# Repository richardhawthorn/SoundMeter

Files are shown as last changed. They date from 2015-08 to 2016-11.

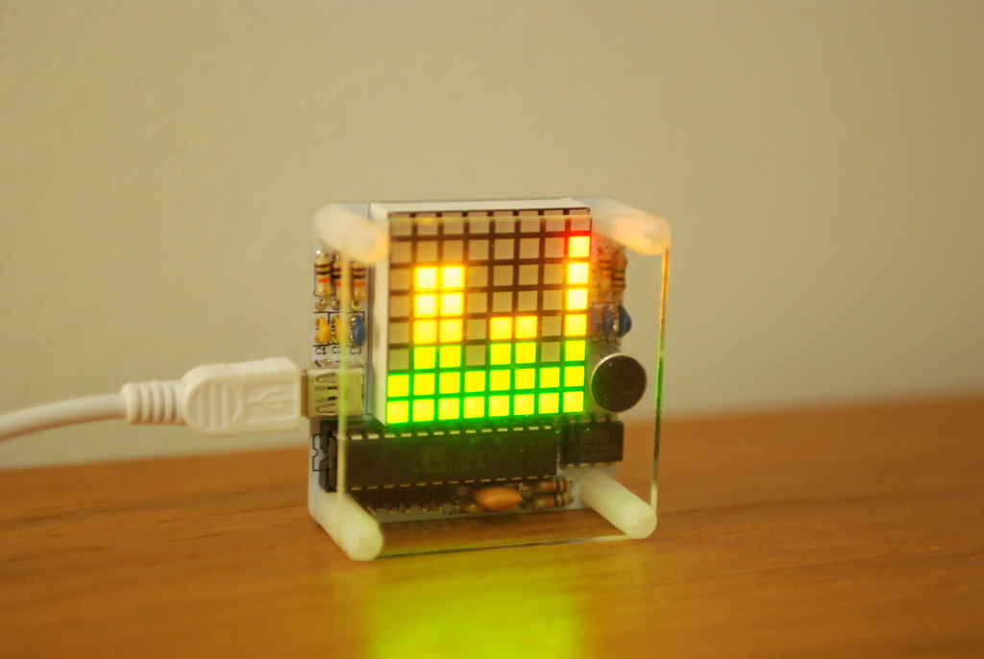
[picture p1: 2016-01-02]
images/DSC_5983.JPG

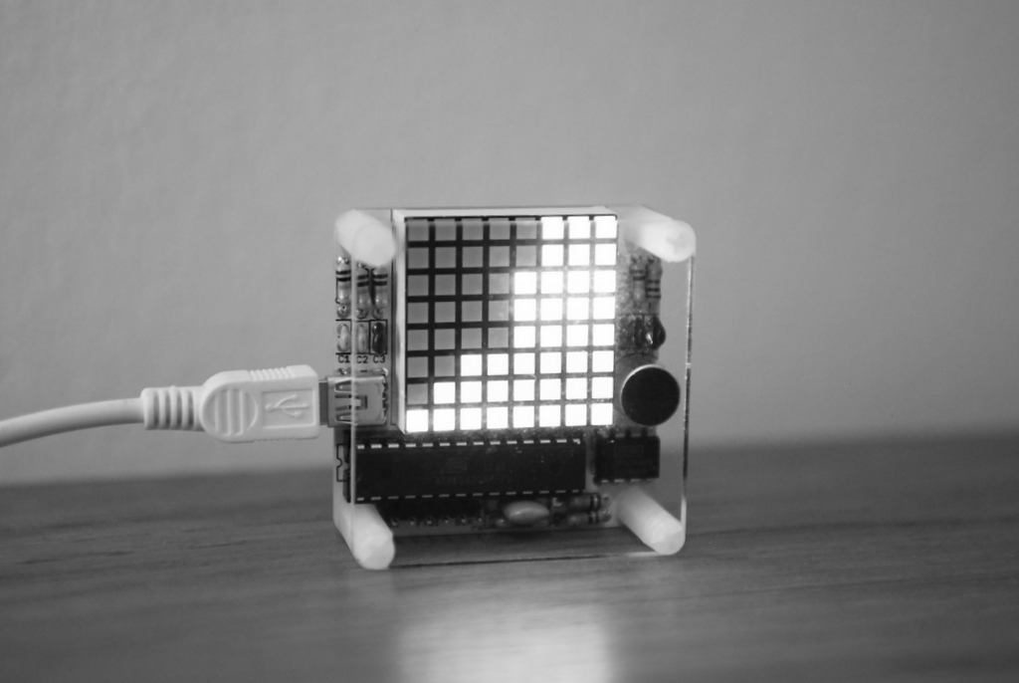
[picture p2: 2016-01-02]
images/DSC_5989.JPG

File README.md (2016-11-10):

### Description

PCB and Arduino code for a sound level meter.  Can be used as a spectrum analyser, or as a scrolling sound level meter.

### Features

- Bi-colour 8x8 LED matrix
- Microphone and built in amplifier
- ATMEGA328P with Arduino boot-loader
- 5V operation @ 16Mhz
- Mini USB power connector
- FTDI programming port
- ICSP port

### License

This work is licensed under a Creative Commons Attribution-ShareAlike 4.0 International License.

<br />
Designed by <a xmlns:cc="http://creativecommons.org/ns#" href="http://www.richardhawthorn.com" property="cc:attributionName" rel="cc:attributionURL" target="_blank">Richard Hawthorn</a><br />
<a rel="license" href="http://creativecommons.org/licenses/by-sa/4.0/" target="_blank">View License</a>

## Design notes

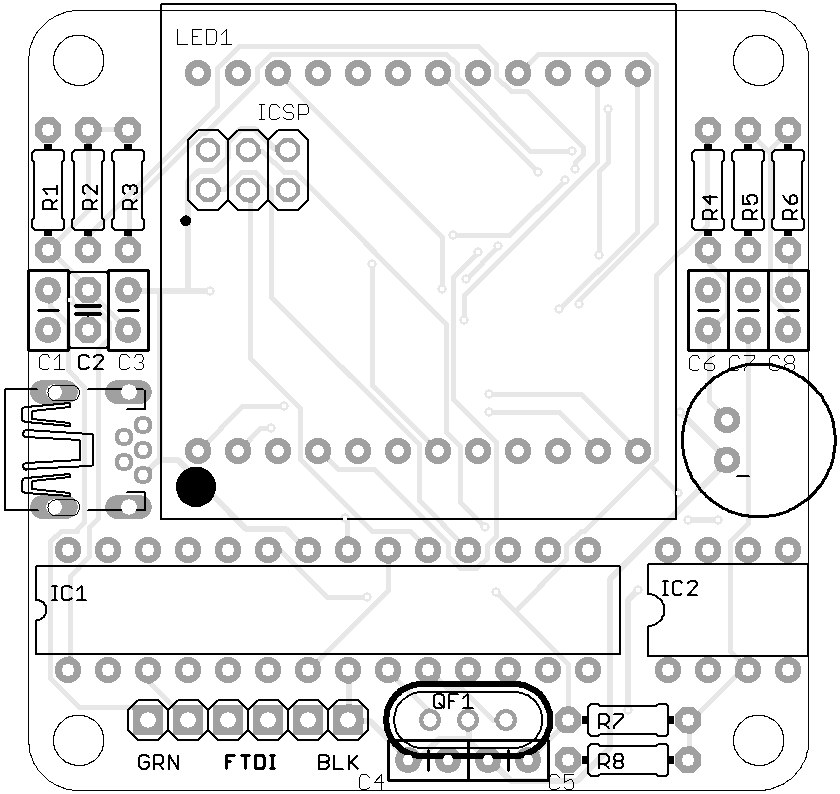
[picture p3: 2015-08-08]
images/pcb_front.png

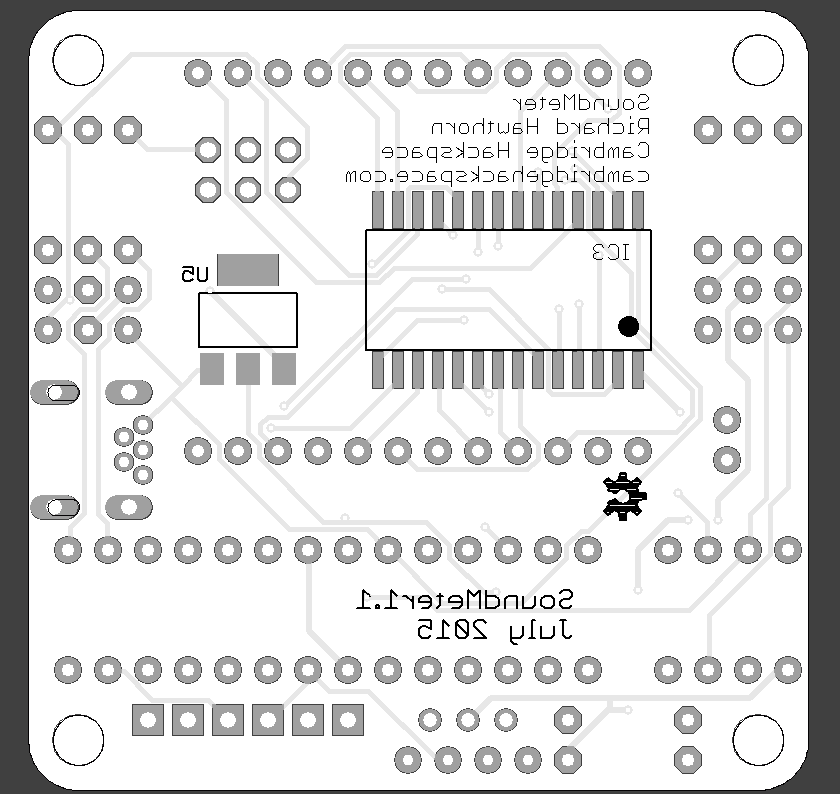
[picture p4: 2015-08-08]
images/pcb_back.png

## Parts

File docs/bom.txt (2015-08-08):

Qty Value      Device                                       Package                    Parts              Description                                                    
1              DISP_SEGMENT_8X8_BICOLOR                     SEGMENT_BICOL              LED1               8x8 Bi-Color LED Segment Displays: Row = Cathode               
3   0.1uf      CAPPTH2                                      CAP-PTH-SMALL2             C1, C2, C4, C5     Capacitor                                                                                          
5   10K        R-US_0204/7                                  0204/7                     R1, R2, R3, R7, R8 RESISTOR, American symbol                                      
1   10k        R-US_0204/7                                  0204/7                     R5                 RESISTOR, American symbol                                      
1   10uf       CAPPTH2                                      CAP-PTH-SMALL2             C3                 Capacitor                                                      
1   12pf       CAPPTH2                                      CAP-PTH-SMALL2             C8                 Capacitor                                                      
1   1M         R-US_0204/7                                  0204/7                     R6                 RESISTOR, American symbol                                      
1   1uf        CAPPTH2                                      CAP-PTH-SMALL2             C7                 Capacitor                                                      
1   28-SOIC    HT16K33_SOP28                                SOP28_300MIL               IC3                                                                               
1   2k2        R-US_0204/7                                  0204/7                     R4                 RESISTOR, American symbol                                      
1   4.7uf      CAPPTH2                                      CAP-PTH-SMALL2             C6                 Capacitor                                                      
1   8M10AHC49T 8M10AHC49T                                   HC49U                      QF1                Monolithic Crystal Filters                                     
1   ATMEGA     ATMEGA168PROUND                              DIL28-3-ROUND              IC1                MICROCONTROLLER                                                
1   FTDI       PINHD-1X6                                    1X06                       CN4                PIN HEADER                                                     
1   ICSP       PINHD-2X3                                    2X03                       ICSP1              PIN HEADER                                                     
1   MIC9.7MM   MIC9.7MM                                     MIC-9.7MM                  U$6                Omni-directional electret microphone. 9.7mm standard diameter. 
1   OPA344     OPA344                                       DIL08                      IC2                OPA344                                                         
1   REG1117    REG1117                                      SOT223                     U5                 800mA and 1A Low Dropout (LDO) Positive Regulator              
1   USB        MINI-USB_SHIELD5P2-32005-601                 32005-601                  X1                 MINI USB-B R/A DIP 5pol.

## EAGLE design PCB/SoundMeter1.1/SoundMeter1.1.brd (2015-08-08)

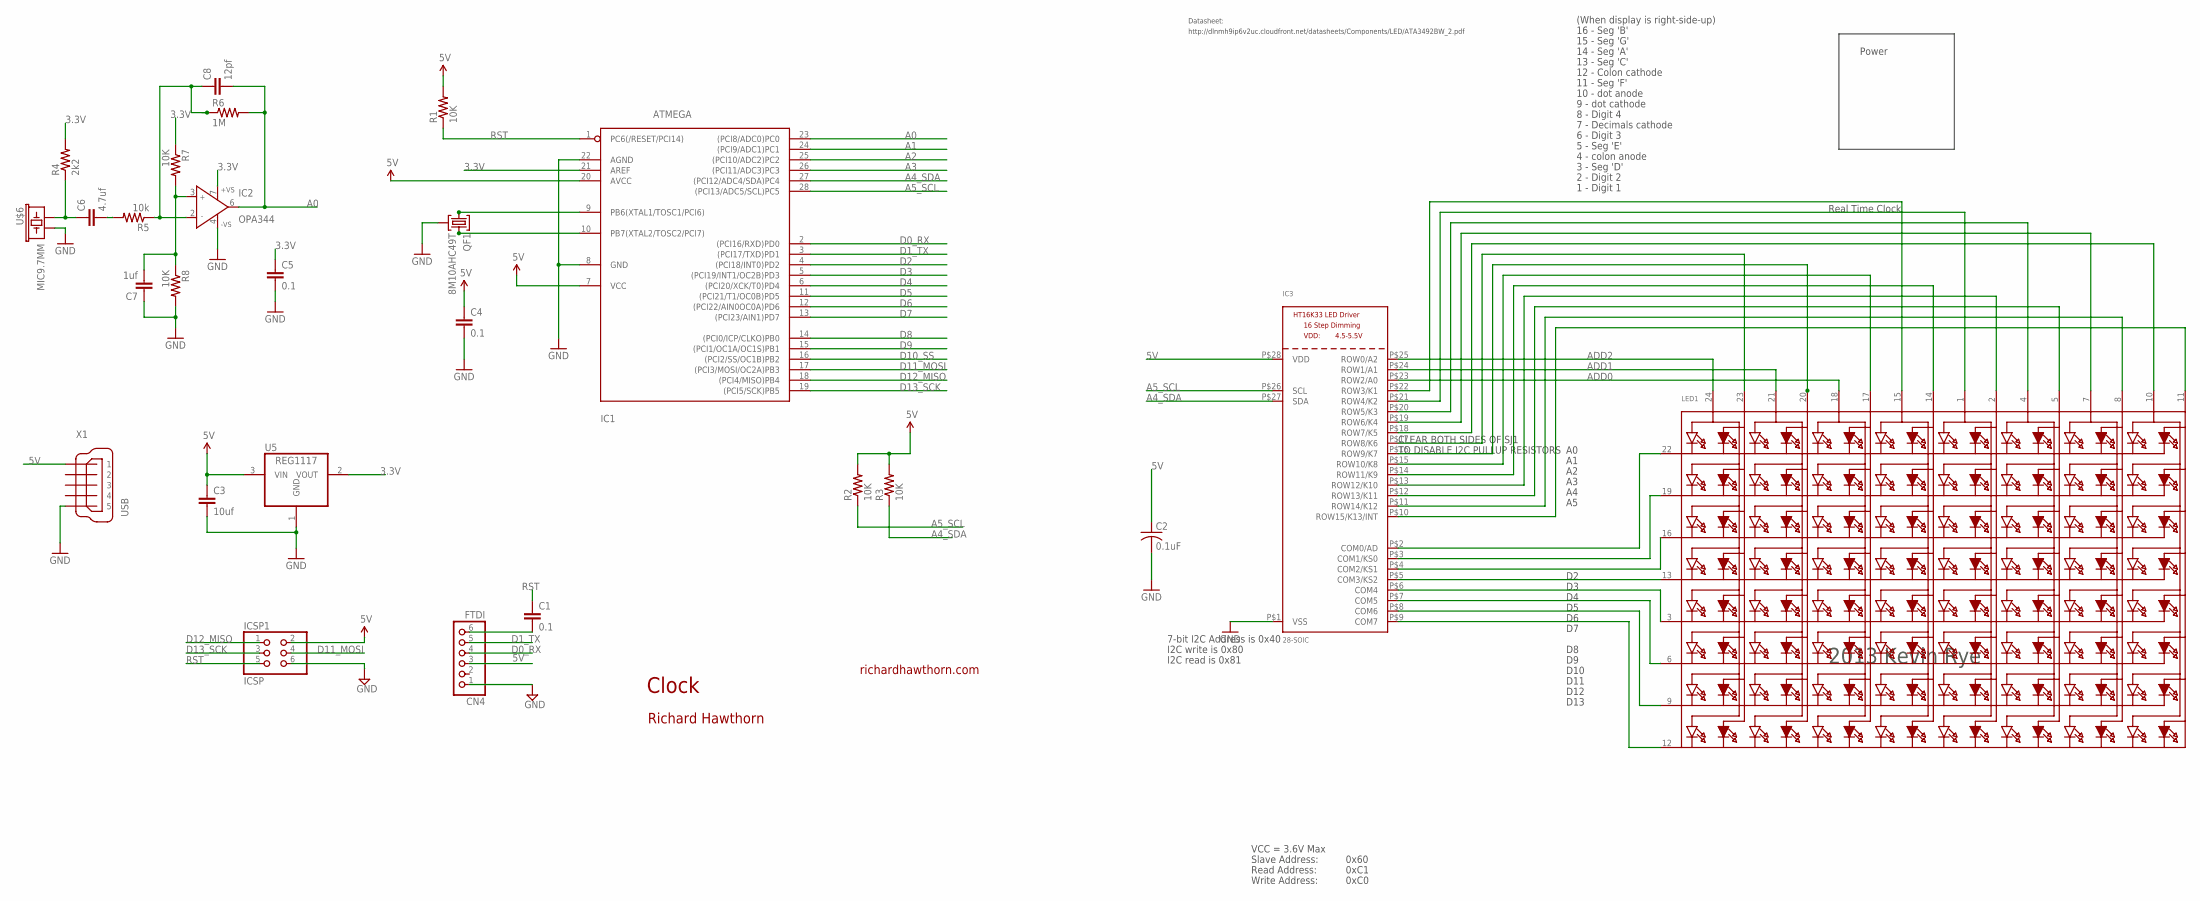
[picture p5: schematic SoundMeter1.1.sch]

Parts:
C1, C4, C5: 0.1; CAP-PTH-SMALL2
C2: 0.1uF; C025-025X050
C3: 10uf; CAP-PTH-SMALL2
C6: 4.7uf; CAP-PTH-SMALL2
C7: 1uf; CAP-PTH-SMALL2
C8: 12pf; CAP-PTH-SMALL2
CN4: FTDI; 1X06
IC1: ATMEGA; DIL28-3-ROUND
IC2: OPA344; DIL08
IC3: 28-SOIC; SOP28_300MIL
ICSP1: ICSP; 2X03
LED1: DISP_SEGMENT_8X8_BICOLOR_ROWCATHODEMI2A883XX; SEGMENT_BICOL_BL-M12A883XX
QF1: 8M10AHC49T; HC49U
R1, R2, R3, R7, R8: 10K; 0204/7
R4: 2k2; 0204/7
R5: 10k; 0204/7
R6: 1M; 0204/7
U5: REG1117; SOT223
U$6: MIC9.7MM; MIC-9.7MM
X1: USB; 32005-601

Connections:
3.3V: C5.1, IC1.21 (AREF), IC2.7 (+VS), R4.2, R7.1, U5.2 (VOUT)
5V: C2.1, C3.1, C4.1, CN4.3, IC1.7 (VCC), IC1.20 (AVCC), IC3.P$28 (VDD), ICSP1.2, R1.2, R2.2, R3.2, U5.3 (VIN), X1.1
A0: C8.2, IC1.23 ((PCI8/ADC0)PC0), IC2.6 (OUT), R6.2
A1: IC1.24 ((PCI9/ADC1)PC1)
A2: IC1.25 ((PCI10/ADC2)PC2)
A3: IC1.26 ((PCI11/ADC3)PC3)
A4_SDA: IC1.27 ((PCI12/ADC4/SDA)PC4), IC3.P$27 (SDA), R3.1
A5_SCL: IC1.28 ((PCI13/ADC5/SCL)PC5), IC3.P$26 (SCL), R2.1
ADD0: IC3.P$23 (ROW2/A0), LED1.18 (A5)
ADD1: IC3.P$24 (ROW1/A1), LED1.21 (A3)
ADD2: IC3.P$25 (ROW0/A2), LED1.24 (A1)
COM: IC3.P$2 (COM0/AD), LED1.22 (K1)
D0_RX: CN4.4, IC1.2 ((PCI16/RXD)PD0)
D1_TX: CN4.5, IC1.3 ((PCI17/TXD)PD1)
D2: IC1.4 ((PCI18/INT0)PD2)
D3: IC1.5 ((PCI19/INT1/OC2B)PD3)
D4: IC1.6 ((PCI20/XCK/T0)PD4)
D5: IC1.11 ((PCI21/T1/OC0B)PD5)
D6: IC1.12 ((PCI22/AIN0OC0A)PD6)
D7: IC1.13 ((PCI23/AIN1)PD7)
D8: IC1.14 ((PCI0/ICP/CLKO)PB0)
D9: IC1.15 ((PCI1/OC1A/OC1S)PB1)
D10_SS: IC1.16 ((PCI2/SS/OC1B)PB2)
D11_MOSI: IC1.17 ((PCI3/MOSI/OC2A)PB3), ICSP1.4
D12_MISO: IC1.18 ((PCI4/MISO)PB4), ICSP1.1
D13_SCK: IC1.19 ((PCI5/SCK)PB5), ICSP1.3
GND: C2.2, C3.2, C4.2, C5.2, C7.1, CN4.1, IC1.8 (GND), IC1.22 (AGND), IC2.4 (-VS), IC3.P$1 (VSS), ICSP1.6, QF1.2, R8.2, U5.1 (GND), U$6.2, X1.5
unnamed: C6.2, R5.2
unnamed: IC3.P$9 (COM7), LED1.12 (K8)
unnamed: C8.1, IC2.2 (IN-), R5.1, R6.1
unnamed: IC3.P$8 (COM6), LED1.9 (K7)
unnamed: C6.1, R4.1, U$6.1
unnamed: C7.2, IC2.3 (IN+), R7.2, R8.1
unnamed: IC3.P$7 (COM5), LED1.6 (K6)
unnamed: IC3.P$6 (COM4), LED1.3 (K5)
unnamed: IC3.P$5 (COM3/KS2), LED1.13 (K4)
unnamed: IC3.P$4 (COM2/KS1), LED1.16 (K3)
unnamed: IC3.P$3 (COM1/KS0), LED1.19 (K2)
unnamed: IC3.P$11 (ROW14/K12), LED1.8 (A14)
unnamed: IC3.P$12 (ROW13/K11), LED1.5 (A12)
unnamed: IC1.9 (PB6(XTAL1/TOSC1/PCI6)), QF1.1
unnamed: C1.2, CN4.6
unnamed: IC3.P$18 (ROW7/K5), LED1.10 (A15)
unnamed: IC3.P$19 (ROW6/K4), LED1.7 (A13)
unnamed: IC1.10 (PB7(XTAL2/TOSC2/PCI7)), QF1.3
unnamed: IC3.P$21 (ROW4/K2), LED1.1 (A9)
unnamed: IC3.P$22 (ROW3/K1), LED1.15 (A7)
unnamed: IC3.P$10 (ROW15/K13/INT), LED1.11 (A16)
unnamed: IC3.P$20 (ROW5/K3), LED1.4 (A11)
unnamed: IC3.P$17 (ROW8/K6), LED1.23 (A2)
unnamed: IC3.P$16 (ROW9/K7), LED1.20 (A4)
unnamed: IC3.P$14 (ROW11/K9), LED1.14 (A8)
unnamed: IC3.P$15 (ROW10/K8), LED1.17 (A6)
unnamed: IC3.P$13 (ROW12/K10), LED1.2 (A10)
RST: C1.1, IC1.1 (PC6(/RESET/PCI14)), ICSP1.5, R1.1

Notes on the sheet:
Clock
richardhawthorn.com
Richard Hawthorn
CLEAR BOTH SIDES OF SJ1
TO DISABLE I2C PULLUP RESISTORS
7-bit I2C Address is 0x40
I2C write is 0x80
I2C read is 0x81
VCC = 3.6V Max
Read Address:
Write Address:
Slave Address:
0x60
0xC1
0xC0
14 - Seg 'A'
13 - Seg 'C'
12 - Colon cathode
11 - Seg 'F'
10 - dot anode
9 - dot cathode
8 - Digit 4
7 - Decimals cathode
6 - Digit 3
5 - Seg 'E'
4 - colon anode
3 - Seg 'D'
2 - Digit 2
Real Time Clock
1 - Digit 1
15 - Seg 'G'
16 - Seg 'B'
D10
D11
D12
D13
http://dlnmh9ip6v2uc.cloudfront.net/datasheets/Components/LED/ATA3492BW_2.pdf
Datasheet:
Power
(When display is right-side-up)

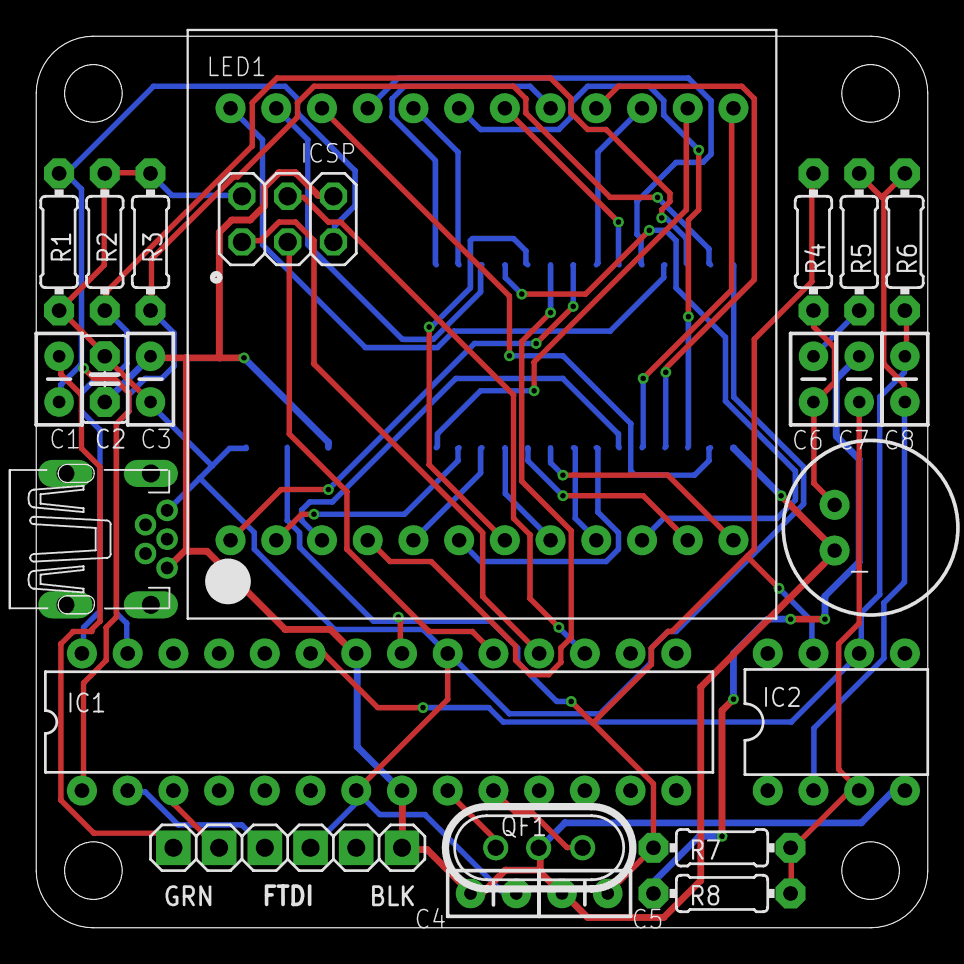
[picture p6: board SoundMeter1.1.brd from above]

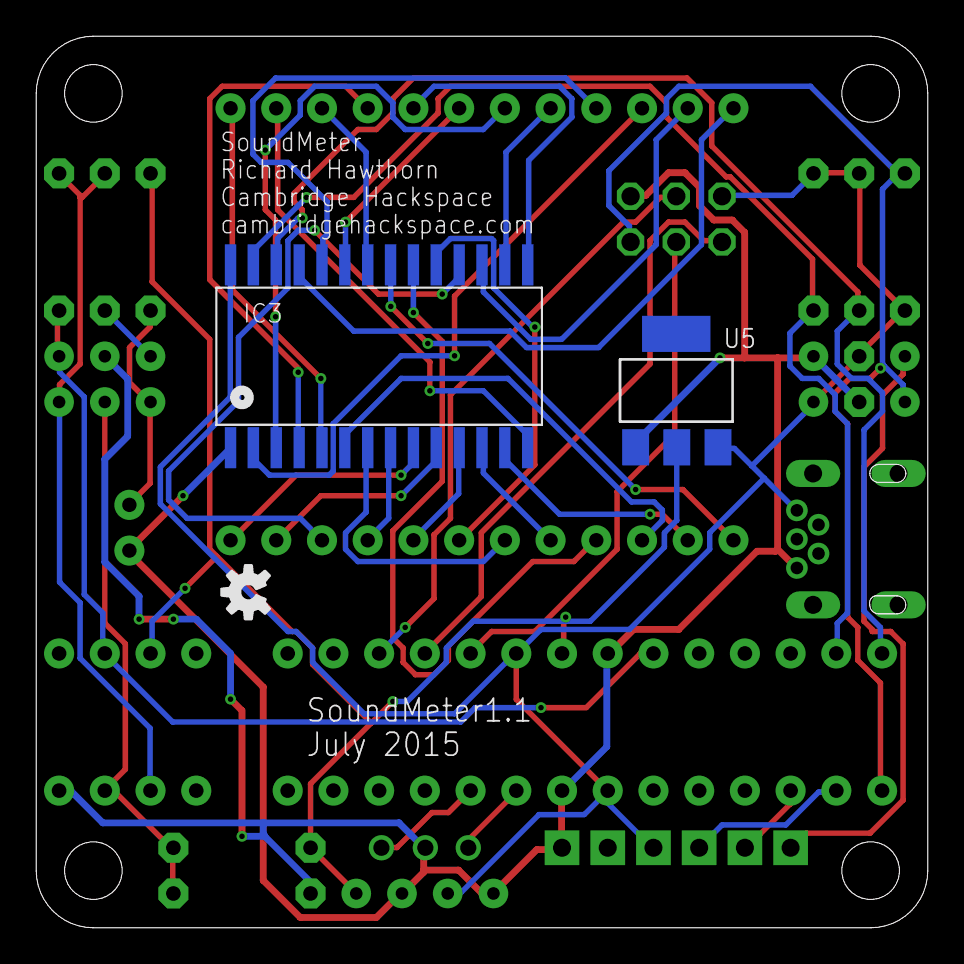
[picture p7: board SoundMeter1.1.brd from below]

Board: 2 copper layers, 49.5 x 49.5 mm, 27 parts (3 on the bottom side), 43 nets.

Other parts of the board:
U$3: OSHW-LOGO-S

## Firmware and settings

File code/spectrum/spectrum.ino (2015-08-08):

/*

PICCOLO is a tiny Arduino-based audio visualizer.

Hardware requirements:
 - Most Arduino or Arduino-compatible boards (ATmega 328P or better).
 - Adafruit Bicolor LED Matrix with I2C Backpack (ID: 902)
 - Adafruit Electret Microphone Amplifier (ID: 1063)
 - Optional: battery for portable use (else power through USB)
Software requirements:
 - elm-chan's ffft library for Arduino

Connections:
 - 3.3V to mic amp+ and Arduino AREF pin <-- important!
 - GND to mic amp-
 - Analog pin 0 to mic amp output
 - +5V, GND, SDA (or analog 4) and SCL (analog 5) to I2C Matrix backpack

Written by Adafruit Industries.  Distributed under the BSD license --
see license.txt for more information.  This paragraph must be included
in any redistribution.

ffft library is provided under its own terms -- see ffft.S for specifics.
*/

// IMPORTANT: FFT_N should be #defined as 128 in ffft.h.

#include <avr/pgmspace.h>
#include <ffft.h>
#include <math.h>
#include <Wire.h>
#include <Adafruit_GFX.h>
#include <Adafruit_LEDBackpack.h>

// Microphone connects to Analog Pin 0.  Corresponding ADC channel number
// varies among boards...it's ADC0 on Uno and Mega, ADC7 on Leonardo.
// Other boards may require different settings; refer to datasheet.
#ifdef __AVR_ATmega32U4__
 #define ADC_CHANNEL 0
#else
 #define ADC_CHANNEL 0
#endif

int16_t       capture[FFT_N];    // Audio capture buffer
complex_t     bfly_buff[FFT_N];  // FFT "butterfly" buffer
uint16_t      spectrum[FFT_N/2]; // Spectrum output buffer
volatile byte samplePos = 0;     // Buffer position counter

byte
  peak[8],      // Peak level of each column; used for falling dots
  dotCount = 0, // Frame counter for delaying dot-falling speed
  colCount = 0; // Frame counter for storing past column data
int
  col[8][10],   // Column levels for the prior 10 frames
  minLvlAvg[8], // For dynamic adjustment of low & high ends of graph,
  maxLvlAvg[8], // pseudo rolling averages for the prior few frames.
  colDiv[8];    // Used when filtering FFT output to 8 columns

/*
These tables were arrived at through testing, modeling and trial and error,
exposing the unit to assorted music and sounds.  But there's no One Perfect
EQ Setting to Rule Them All, and the graph may respond better to some
inputs than others.  The software works at making the graph interesting,
but some columns will always be less lively than others, especially
comparing live speech against ambient music of varying genres.
*/
static const uint8_t PROGMEM
  // This is low-level noise that's subtracted from each FFT output column:
  noise[64]={ 8,6,6,5,3,4,4,4,3,4,4,3,2,3,3,4,
              2,1,2,1,3,2,3,2,1,2,3,1,2,3,4,4,
              3,2,2,2,2,2,2,1,3,2,2,2,2,2,2,2,
              2,2,2,2,2,2,2,2,2,2,2,2,2,3,3,4 },
  // These are scaling quotients for each FFT output column, sort of a
  // graphic EQ in reverse.  Most music is pretty heavy at the bass end.
  eq[64]={
    255, 175,218,225,220,198,147, 99, 68, 47, 33, 22, 14,  8,  4,  2,
      0,   0,  0,  0,  0,  0,  0,  0,  0,  0,  0,  0,  0,  0,  0,  0,
      0,   0,  0,  0,  0,  0,  0,  0,  0,  0,  0,  0,  0,  0,  0,  0,
      0,   0,  0,  0,  0,  0,  0,  0,  0,  0,  0,  0,  0,  0,  0,  0 },
  // When filtering down to 8 columns, these tables contain indexes
  // and weightings of the FFT spectrum output values to use.  Not all
  // buckets are used -- the bottom-most and several at the top are
  // either noisy or out of range or generally not good for a graph.
  col0data[] = {  2,  1,  // # of spectrum bins to merge, index of first
    111,   8 },           // Weights for each bin
  col1data[] = {  4,  1,  // 4 bins, starting at index 1
     19, 186,  38,   2 }, // Weights for 4 bins.  Got it now?
  col2data[] = {  5,  2,
     11, 156, 118,  16,   1 },
  col3data[] = {  8,  3,
      5,  55, 165, 164,  71,  18,   4,   1 },
  col4data[] = { 11,  5,
      3,  24,  89, 169, 178, 118,  54,  20,   6,   2,   1 },
  col5data[] = { 17,  7,
      2,   9,  29,  70, 125, 172, 185, 162, 118, 74,
     41,  21,  10,   5,   2,   1,   1 },
  col6data[] = { 25, 11,
      1,   4,  11,  25,  49,  83, 121, 156, 180, 185,
    174, 149, 118,  87,  60,  40,  25,  16,  10,   6,
      4,   2,   1,   1,   1 },
  col7data[] = { 37, 16,
      1,   2,   5,  10,  18,  30,  46,  67,  92, 118,
    143, 164, 179, 185, 184, 174, 158, 139, 118,  97,
     77,  60,  45,  34,  25,  18,  13,   9,   7,   5,
      3,   2,   2,   1,   1,   1,   1 },
  // And then this points to the start of the data for each of the columns:
  * const colData[]  = {
    col0data, col1data, col2data, col3data,
    col4data, col5data, col6data, col7data };

Adafruit_BicolorMatrix matrix = Adafruit_BicolorMatrix();

void setup() {
  uint8_t i, j, nBins, binNum, *data;

  memset(peak, 0, sizeof(peak));
  memset(col , 0, sizeof(col));

  for(i=0; i<8; i++) {
    minLvlAvg[i] = 0;
    maxLvlAvg[i] = 512;
    data         = (uint8_t *)pgm_read_word(&colData[i]);
    nBins        = pgm_read_byte(&data[0]) + 2;
    binNum       = pgm_read_byte(&data[1]);
    for(colDiv[i]=0, j=2; j<nBins; j++)
      colDiv[i] += pgm_read_byte(&data[j]);
  }

  matrix.begin(0x70);

  // Init ADC free-run mode; f = ( 16MHz/prescaler ) / 13 cycles/conversion 
  ADMUX  = ADC_CHANNEL; // Channel sel, right-adj, use AREF pin
  ADCSRA = _BV(ADEN)  | // ADC enable
           _BV(ADSC)  | // ADC start
           _BV(ADATE) | // Auto trigger
           _BV(ADIE)  | // Interrupt enable
           _BV(ADPS2) | _BV(ADPS1) | _BV(ADPS0); // 128:1 / 13 = 9615 Hz
  ADCSRB = 0;                // Free run mode, no high MUX bit
  DIDR0  = 1 << ADC_CHANNEL; // Turn off digital input for ADC pin
  TIMSK0 = 0;                // Timer0 off

  sei(); // Enable interrupts
}

void loop() {
  uint8_t  i, x, L, *data, nBins, binNum, weighting, c;
  uint16_t minLvl, maxLvl;
  int      level, y, sum;

  while(ADCSRA & _BV(ADIE)); // Wait for audio sampling to finish

  fft_input(capture, bfly_buff);   // Samples -> complex #s
  samplePos = 0;                   // Reset sample counter
  ADCSRA |= _BV(ADIE);             // Resume sampling interrupt
  fft_execute(bfly_buff);          // Process complex data
  fft_output(bfly_buff, spectrum); // Complex -> spectrum

  // Remove noise and apply EQ levels
  for(x=0; x<FFT_N/2; x++) {
    L = pgm_read_byte(&noise[x]);
    spectrum[x] = (spectrum[x] <= L) ? 0 :
      (((spectrum[x] - L) * (256L - pgm_read_byte(&eq[x]))) >> 8);
  }

  // Fill background w/colors, then idle parts of columns will erase
  matrix.fillRect(0, 0, 8, 3, LED_RED);    // Upper section
  matrix.fillRect(0, 3, 8, 2, LED_YELLOW); // Mid
  matrix.fillRect(0, 5, 8, 3, LED_GREEN);  // Lower section

  // Downsample spectrum output to 8 columns:
  for(x=0; x<8; x++) {
    data   = (uint8_t *)pgm_read_word(&colData[x]);
    nBins  = pgm_read_byte(&data[0]) + 2;
    binNum = pgm_read_byte(&data[1]);
    for(sum=0, i=2; i<nBins; i++)
      sum += spectrum[binNum++] * pgm_read_byte(&data[i]); // Weighted
    col[x][colCount] = sum / colDiv[x];                    // Average
    minLvl = maxLvl = col[x][0];
    for(i=1; i<10; i++) { // Get range of prior 10 frames
      if(col[x][i] < minLvl)      minLvl = col[x][i];
      else if(col[x][i] > maxLvl) maxLvl = col[x][i];
    }
    // minLvl and maxLvl indicate the extents of the FFT output, used
    // for vertically scaling the output graph (so it looks interesting
    // regardless of volume level).  If they're too close together though
    // (e.g. at very low volume levels) the graph becomes super coarse
    // and 'jumpy'...so keep some minimum distance between them (this
    // also lets the graph go to zero when no sound is playing):
    if((maxLvl - minLvl) < 8) maxLvl = minLvl + 8;
    minLvlAvg[x] = (minLvlAvg[x] * 7 + minLvl) >> 3; // Dampen min/max levels
    maxLvlAvg[x] = (maxLvlAvg[x] * 7 + maxLvl) >> 3; // (fake rolling average)

    // Second fixed-point scale based on dynamic min/max levels:
    level = 10L * (col[x][colCount] - minLvlAvg[x]) /
      (long)(maxLvlAvg[x] - minLvlAvg[x]);

    // Clip output and convert to byte:
    if(level < 0L)      c = 0;
    else if(level > 10) c = 10; // Allow dot to go a couple pixels off top
    else                c = (uint8_t)level;

    if(c > peak[x]) peak[x] = c; // Keep dot on top

    if(peak[x] <= 0) { // Empty column?
      matrix.drawLine(x, 0, x, 7, LED_OFF);
      continue;
    } else if(c < 8) { // Partial column?
      matrix.drawLine(x, 0, x, 7 - c, LED_OFF);
    }

    // The 'peak' dot color varies, but doesn't necessarily match
    // the three screen regions...yellow has a little extra influence.
    y = 8 - peak[x];
    if(y < 2)      matrix.drawPixel(x, y, LED_RED);
    else if(y < 6) matrix.drawPixel(x, y, LED_YELLOW);
    else           matrix.drawPixel(x, y, LED_GREEN);
  }

  matrix.writeDisplay();

  // Every third frame, make the peak pixels drop by 1:
  if(++dotCount >= 3) {
    dotCount = 0;
    for(x=0; x<8; x++) {
      if(peak[x] > 0) peak[x]--;
    }
  }

  if(++colCount >= 10) colCount = 0;
}

ISR(ADC_vect) { // Audio-sampling interrupt
  static const int16_t noiseThreshold = 4;
  int16_t              sample         = ADC; // 0-1023

  capture[samplePos] =
    ((sample > (512-noiseThreshold)) &&
     (sample < (512+noiseThreshold))) ? 0 :
    sample - 512; // Sign-convert for FFT; -512 to +511

  if(++samplePos >= FFT_N) ADCSRA &= ~_BV(ADIE); // Buffer full, interrupt off
}

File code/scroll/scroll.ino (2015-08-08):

/****************************************
Scrolling sound level meter
Richard Hawthorn
richardhawthorn.com
Cambridge Hackspace
Aug 2015
For use with SoundMeter board
Based on code from Adafruit
****************************************/
 
#include <Wire.h>
#include "Adafruit_LEDBackpack.h"
#include "Adafruit_GFX.h"
 
// Include the Matrix code
Adafruit_BicolorMatrix matrix = Adafruit_BicolorMatrix();
 
const int maxScale = 8;
const int redZone = 6;
const int yellowZone = 3;
 
const int sampleWindow = 50; // Sample window width in mS (50 mS = 20Hz)
unsigned int sample;
 
void setup() 
{
   analogReference(EXTERNAL); //use external voltage reference
   matrix.begin(0x70);  // start the matrix display
}
 
void loop() 
{
   unsigned long startMillis = millis();  // Start of sample window
   unsigned int peakToPeak = 0;   // peak-to-peak level
 
   unsigned int signalMax = 0;
   unsigned int signalMin = 1024;
 
   //sample for a set period of time
   while (millis() - startMillis < sampleWindow)
   {
      sample = analogRead(0); 
      
      if (sample < 1024) //make sure we are in the right range
      {
         if (sample > signalMax)
         {
            signalMax = sample;  // save max value
         }
         else if (sample < signalMin)
         {
            signalMin = sample; //save sample value
         }
      }
   }
   peakToPeak = signalMax - signalMin;
   
   // map the peaks to the scale
   int displayPeak = map(peakToPeak, 0, 1023, 0, maxScale);
 
   // shift the previous values left
   for (int i = 0; i < 8; i++)
   {
      matrix.displaybuffer[i] = (matrix.displaybuffer[i] >> 1);
   }
 
   // draw the new value
   for (int i = 0; i <= maxScale; i++)
   {
      if (i >= displayPeak)
      {
         matrix.drawPixel(7, 7-i, 0);
      }
      else if (i < yellowZone) // green
      {
         matrix.drawPixel(7, 7-i, LED_GREEN);
      }
      else if (i < redZone) // yellow
      {
         matrix.drawPixel(7, 7-i, LED_YELLOW);
      }
      else // red
      {
         matrix.drawPixel(7, 7-i, LED_RED);
      }
   }
   matrix.writeDisplay();  // write the changes we just made to the display
}

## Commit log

2015-08-08 add pcb and images
    [SoundMeter1.1.brd, SoundMeter1.1.sch]
2015-08-08 add bom and code examples

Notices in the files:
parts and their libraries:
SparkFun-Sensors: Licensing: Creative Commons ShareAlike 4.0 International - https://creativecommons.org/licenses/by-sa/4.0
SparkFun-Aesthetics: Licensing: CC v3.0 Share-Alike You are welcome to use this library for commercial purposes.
